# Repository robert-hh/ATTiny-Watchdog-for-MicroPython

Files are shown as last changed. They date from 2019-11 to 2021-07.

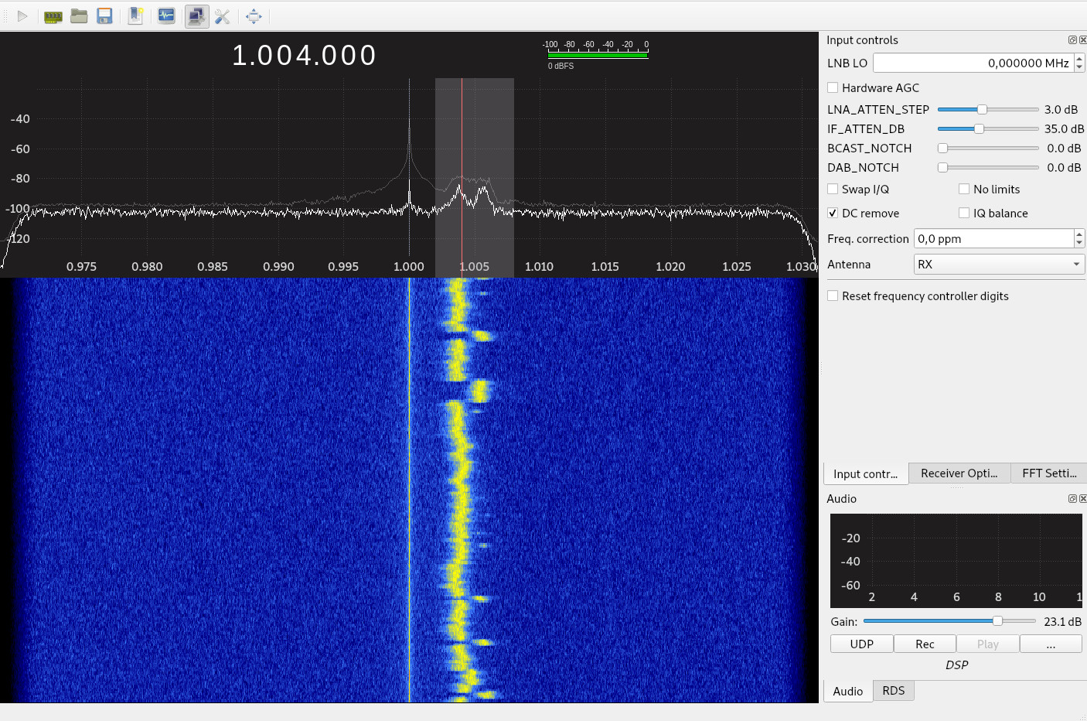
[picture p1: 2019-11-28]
Clock_1MHz.jpg

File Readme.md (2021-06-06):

# ATTiny based Watchdog (for MicroPython devices)

These are two variants of an external watchdog, which I made for use with ES32 based MicroPython
devices. Even if the ESP32 has a built-in watchdog, it is not really reliable. Actually, using
it does not improve the long term reliability of an application.

These two variants consists of two components:

- Software for an AttinyX5 device, which is the actual Watchdog. For (my) convenience
I made it with the Arduino development environment. I selected the ATTiny because it is easy 
available, cheap, well documented, and easy to use and available in various packages. 
Besides the controller and a pull-up resistor for the input, no other component is required.
- A small class for the MicroPython device controlling the watchdog.

These two variants differ on how the communication between the micropython device and
the watchdog is done.

- Pulse: Communication to the watchdog is via one GPIO line and pulses of various duration. 
That is the only drawback of using an external watchdog: it requires an GPIO port for feeding.
- Serial: Communication to the Watchdog is via one GPIO line and serial commands at 9600 baud.
Since only data is sent, I used the RMT module for sending, saving the UART port. For devices
without RMT a UART based variant is supplied.

The run-time overhead of both variants is comparable and differs only in the length of the 
feed pulse. For the **pulse** variant, it is 20µs, for the **serial** and **uart**  variant,
it is 100µs (the length of the start bit at 9600 baud).

Both watchdogs have two states, a sleep state and a watch state. They start in sleep state and have 
to be armed by a dedicated signal. The watch state can be suspended, e.g. before going to deep sleep.
The current consumption of the watchdog is about 1 µA, with short bursts of 1 mA for 500µs every second.

When the watchdog fires (Barks), it creates reset pulse of 100ms duration. For that time, the 
respective GPIO pin of the ATTiny will set to output mode. In all other times, it is in
input mode with pull-up active.

In both version, an Reset signal on the supervized micro is detected and will cause the watchdog 
to enter the sleep state. If the sleep state is timed (see command stop() below), then for that period only.

## Python class

### Serial version, RMT
watchdog = Watchdog(port, status=None, restart=False, baudrate=9600)

**Port** is the name or number of the GPIO port. It is important not to supply a pin
object, but the name, e.g. "P9" or 14. The GPIO pin will be initialized by the class.  
**status** is the name/number of a pin, which, if connected, can be used to read back the 
status of the watchdog. If the status pin is set,   
**restart**=True will cause a feed signal to be sent when status starts toggling,
which is when the watch period is halfway expired. This is useful in situations, when there is no
suitable place for a feed() call. The drawback: feed() is then called in a callback function, which
may even be executed when the to-be-supervized functions stoppped working.
**baudrate** is the speed to be used. The default is 9600 and hardly ever changed.

### Serial version, UART
watchdog = Watchdog(uart, status=None)

**uart** has be be an UART object created with the proper baud rate and pin assignments.  
**status** is a Pin object, defined in input mode for reading back the status pin.

### Pulse version
watchdog = Watchdog(port, status=None, restart=False)

**Port** is the name or number of the GPIO port. It is important not to supply a pin
object, but the name, e.g. "P9" or 14. The GPIO pin will be initialized by the class.  
**status** is the name/number of a pin, which, if connected, can be used to read back 
the status of the watchdog.  
**restart**=True will cause a feed signal to be sent when status starts toggling,
which is when the watch period is halfway expired. This is useful in situations, when there is no
suitable place for a feed() call. The drawback: feed() is then called in a callback function, which
may even be executed when the to-be-supervized functions stoppped working.  

## Methods

### watchdog.start(seconds)

Set the timeout period of the watchdog to seconds and start the watch mode. The granularity is seconds.
The shortest timeout period that can be set in the pulse version is about 15 seconds.

### watchdog.feed()

Feed the dog. The timeout time will be set to the value given by the start() command.
Do not call feed(), e.g. in a different thread, before the start() command terminated, 
which may take a while. After calling feed(), it takes about 2 ms until the status as reported by a
call to status() changes. 

### watchdog.stop(seconds=0)

Suspend the watch state for the given time and enter the sleep state. 
If the value of seconds is not zero, sleep only for that amount of time 
and return to the watch state after that.

### watchdog.status()

Read back the status of the watchdog using the pin set in the constructor. Return values:  

|Value|Meaning|
|:-:|:-|
|0|The watchdog is sleeping|
|1|The watchdog is active. If the watch period is halfway elapsed, the value gets togggling once per second. That can be used for instance to trigger a callback, which feeds the watchdog.|
|None|Port no set|

### watchdog.send(string)

Send string to the watchdog device using the baud rate set in the constructor. 
That is the basic command used by the methods start() and stop(). 
You can use that to toggle DEBUG output from the watchdog, by calling send("D").
In the pulse version, send() exists but does not do anything.

## Command interface of the ATTiny

### Pin assignments of the Attiny:

|Pin|Port|Function|
|:-:|:-:|:-|
|2|PB3|Reset signal to host (required)|
|3|PB4|Feed and command input pin (recommended)|
|4|GND|GND (required)|
|6|PB1|Status pin (optional)|
|7|PB2|Debug output pin. (optional)|
|8|Vcc|3.3 - 5V Vcc (required)|

### Serial interface

The following commands are supported: 

| Command | Description |
|:-:|:--|
|Snnn|Set the timeout of the watchdog and change to the watch state. nnn is the value in seconds. The command can be repeated while in watch state and will set a new timeout.|
|Pnnn|Suspend the watch state and return to the sleep state. If the number nnn is given and > 0, then sleep for that time only and return to the watch state after that.|
|Dn|n is a number, which may be omitted. If the value is 0, toggle the DEBUG output. If the value is not 0, switch DEBUG ouput on. The output is send to Port PB2 of the ATTiny with 9600 baud.|
|anything else|Feed the dog. For speed, the feed command actually only creates a start bit, and the ATTiny then reads 0xff as character.|

The DEBUG output of the ATTiny will echo the command and countdown the time in watch mode.  
The status output will indicate the watchdog state; low for sleeping and high for watching.

For the serial version a pull-up resistor at the communication link is highly recommended. The serial 
interface in the ATTiny uses the SoftSerial module of Arduino. It depends on the internal clock of 
the ATTiny (1 MHz here), which is not 100% accurate. In my test, the clock speed was 
about 1.005 MHz +/- 2 KHz. For asynchronous serial, that is still within the tolerated error range.

### Pulse interface

The following pulse time ranges are defined: 

|State| Duration| Description |
|:-:|:-:|:--|
|sleep|pulse < 5 ms|Feed pulse. Will be ignored|
|sleep|5 ms <= pulse < 10 ms|Stay in sleep mode. If after less than 10 ms it is followed by another pulse, that time is taken as sleep timeout.|
|sleep|10 ms <= pulse < 3600 ms|Set the timeout of the watchdog and change to the watch state. The pulse duration in ms defines the timeout value in seconds.|
|watch|20 µs < pulse < 5 ms|Feed the dog.| 
|watch|5 ms <= pulse < 10 ms|Suspend the watch state and enter the sleep state. If after less than 10 ms it is followed by another pulse, the length of that pulse is taken as sleep timeout.|
|watch|10 ms <= pulse < 3600 ms|Restart the watch state and set the new timeout.|

Pulses longer that 3600ms will be ignored in both states. That covers a line which is permanently low. The determination of the pulse duration is not very accurate, but good enough for the purpose.

The debug output will respond to the input with a series of pulses.   
- The first pulse length shows, if a internal timeout (~200µs) or a signal from the host (~1 ms) happened.   
- The second pulse shows the state of the watchdog, short for sleep and long for watch.   
- The third pulse shows the state of the reset line, short for high and long for low.  
- That is followed  by a burst of short pulses. The burst length indicates the remaining time until
timeout in the respective state. 

The status output will indicate the watchdog state; low for sleeping and high for watching.

## Example

Basic example:

```
import watchdog

wd = watchdog.Watchdog("P9")
wd.start(100) # set a timeout of 100 seconds and start
#
# To feed, call regularly
#
wd.feed()
#
# to stop, call
#
wd.stop()
```

Basic example using the internal callback for feeding:

```
import watchdog

wd = watchdog.Watchdog("P9", "P10", True)
wd.start(100) # set a timeout of 100 seconds and start
#
# No explicit call to feed is required
#
# to stop, call
#
wd.stop()
```

UART example using an dedicated callback for feeding:

```
import watchdog
from machine import UART, Pin

uart=UART(1, 9600)
pin = Pin("P10", Pin.IN)
wd = watchdog_uart.Watchdog(uart, pin)
pin.callback(Pin.IRQ_FALLING, handler=lambda p: wd.feed())

wd.start(100) # set a timeout of 100 seconds and start
#
# No explicit call to feed is required
#
# to stop, call
#
wd.stop()
```

## License

The MIT License (MIT)

Copyright (c) 2021 RobertHammelrath

Permission is hereby granted, free of charge, to any person obtaining a copy
of this software and associated documentation files (the "Software"), to deal
in the Software without restriction, including without limitation the rights
to use, copy, modify, merge, publish, distribute, sublicense, and/or sell
copies of the Software, and to permit persons to whom the Software is
furnished to do so, subject to the following conditions:
The above copyright notice and this permission notice shall be included in
all copies or substantial portions of the Software.

THE SOFTWARE IS PROVIDED "AS IS", WITHOUT WARRANTY OF ANY KIND, EXPRESS OR
IMPLIED, INCLUDING BUT NOT LIMITED TO THE WARRANTIES OF MERCHANTABILITY,
FITNESS FOR A PARTICULAR PURPOSE AND NONINFRINGEMENT. IN NO EVENT SHALL THE
AUTHORS OR COPYRIGHT HOLDERS BE LIABLE FOR ANY CLAIM, DAMAGES OR OTHER
LIABILITY, WHETHER IN AN ACTION OF CONTRACT, TORT OR OTHERWISE, ARISING FROM,
OUT OF OR IN CONNECTION WITH THE SOFTWARE OR THE USE OR OTHER DEALINGS IN
THE SOFTWARE.

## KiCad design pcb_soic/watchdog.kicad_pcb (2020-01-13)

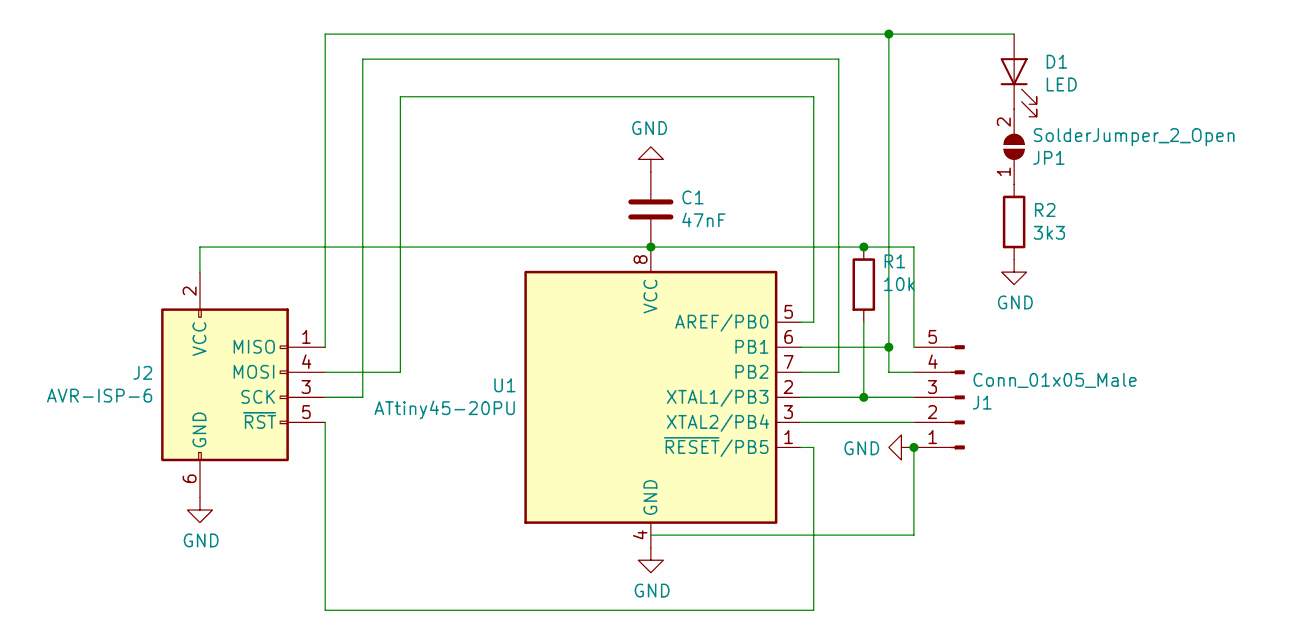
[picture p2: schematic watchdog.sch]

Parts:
C1: 47nF; C_1206_3216Metric_Pad1.42x1.75mm_HandSolder
D1: LED; LED_1206_3216Metric_Pad1.42x1.75mm_HandSolder
J1: Conn_01x05_Male; PinHeader_1x05_P2.54mm_Vertical
J2: AVR-ISP-6; PinHeader_2x03_P2.54mm_Vertical
JP1: SolderJumper_2_Open; SolderJumper-2_P1.3mm_Open_TrianglePad1.0x1.5mm
R1: 10k; R_1206_3216Metric_Pad1.42x1.75mm_HandSolder
R2: 3k3; R_1206_3216Metric_Pad1.42x1.75mm_HandSolder
U1: ATtiny45-20PU; DIP-8_W7.62mm

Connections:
GND: C1.1, J1.1, J2.6 (GND), R2.2, U1.4 (GND)
unnamed: C1.2, J1.5, J2.2 (VCC), R1.1, U1.8 (VCC)
unnamed: D1.1 (K), JP1.2 (B)
unnamed: D1.2 (A), J1.4, J2.1 (MISO), U1.6 (PB1)
unnamed: J1.2, U1.3 (XTAL2/PB4)
unnamed: J1.3, R1.2, U1.2 (XTAL1/PB3)
unnamed: J2.3 (SCK), U1.7 (PB2)
unnamed: J2.4 (MOSI), U1.5 (AREF/PB0)
unnamed: J2.5 (~RST), U1.1 (~RESET~/PB5)
unnamed: JP1.1 (A), R2.1

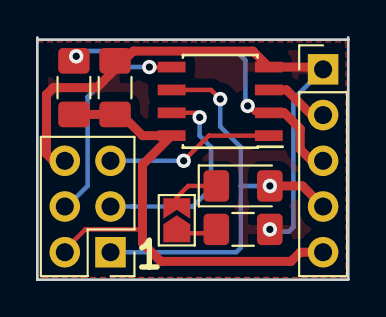
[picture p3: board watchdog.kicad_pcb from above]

Board: 2 copper layers, 17.3 x 13.5 mm, 8 parts (0 on the bottom side), 10 nets.

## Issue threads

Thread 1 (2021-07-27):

wrong pin-numbering in attiny-code for pulse-version

l0j0, 2021-07-27:
it seems the pin numbers in the pulse-version of the attiny code (watchdog.ino) are exchanged:
it reads:
#define FEED_PIN 3
#define DEBUG_PIN 2
#define STATUS_PIN 1
#define RESET_PIN 4

but should be (also according readme and kicad schema):
#define FEED_PIN 4
#define DEBUG_PIN 2
#define STATUS_PIN 1
#define RESET_PIN 3

thanks for this great project btw!

robert-hh, 2021-07-28:
Thank you for the note. It may be, that I changed the pin assignment for an easier Board layout. I'll change that.

robert-hh, 2021-07-29:
Changed. And thank you very much for the hint.

Closed 2021-07-29.

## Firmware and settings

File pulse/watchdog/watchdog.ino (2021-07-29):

/*
 *
 * The MIT License (MIT)
 *
 * Copyright (c) 2021 RobertHammelrath
 *
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
 * THE SOFTWARE IS PROVIDED "AS IS", WITHOUT WARRANTY OF ANY KIND, EXPRESS OR
 * IMPLIED, INCLUDING BUT NOT LIMITED TO THE WARRANTIES OF MERCHANTABILITY,
 * FITNESS FOR A PARTICULAR PURPOSE AND NONINFRINGEMENT. IN NO EVENT SHALL THE
 * AUTHORS OR COPYRIGHT HOLDERS BE LIABLE FOR ANY CLAIM, DAMAGES OR OTHER
 * LIABILITY, WHETHER IN AN ACTION OF CONTRACT, TORT OR OTHERWISE, ARISING FROM,
 * OUT OF OR IN CONNECTION WITH THE SOFTWARE OR THE USE OR OTHER DEALINGS IN
 * THE SOFTWARE.
 */

/* 
   Soft Watchdog Timer
   Receives both Feed pulse and Commands from Pin 4
*/
   
#include <avr/sleep.h>
#include <avr/interrupt.h>
#include <avr/power.h>
#include <avr/wdt.h>

#define FEED_PIN 4
#define DEBUG_PIN 2
#define STATUS_PIN 1
#define RESET_PIN 3

#define DEBUG 0

#define MAX_PULSE 3600
#define SUSPEND_PULSE 5 

// Globals
// if you want to start the watchdog busy, set sleep period and watch period accordingly.
// then it needs no further interaction to run.
//
int watch_period = 3600; // Default timeout 1 hour. Sleepy dog
int sleep_period = 0;    // Default timeout infinite
int timer = sleep_period;
int tick_seen = 0;
enum {
  SLEEPING, WATCHING
} state = SLEEPING; 

enum tags {
  TIMEOUT = 'T',
  START = 'S',
  STOP = 'P',
  FEED = 'F',
  LOGGING = 'D'
};

// Function and Data Prototypes
struct result {
    tags cmd;
    int value;
};
void system_sleep(int duration, int mode) ;
int get_pulsetime(int, int, int);
result get_input();
#if DEBUG
void send_ack(int, int);
void send_burst(int, int);
#endif

void setup() {
    pinMode(RESET_PIN, INPUT_PULLUP);
    pinMode(FEED_PIN, INPUT_PULLUP);
    pinMode(STATUS_PIN, OUTPUT);
#if DEBUG
    pinMode(DEBUG_PIN, OUTPUT);
#endif
    state = SLEEPING;
}

void loop() {
    result input;
    int reset_state;

    if (state == SLEEPING) {
      digitalWrite(STATUS_PIN, LOW);
    } else {
      if (timer < (watch_period / 2)) {
        digitalWrite(STATUS_PIN, timer & 1); // toggle status
      } else {
        digitalWrite(STATUS_PIN, HIGH);
      }
    }

    system_sleep(WDTO_1S, SLEEP_MODE_PWR_DOWN);

    reset_state = digitalRead(RESET_PIN); // could be reset of the master which happened
    input = get_input();
    if (reset_state == 0) { // reset forces Sleep or Feed??
        state = SLEEPING;
        timer = sleep_period;
    } else {
      switch (input.cmd) {
        case START:
          state = WATCHING;
          timer = watch_period = input.value;
          break;
        case STOP:
          state = SLEEPING;
          timer = sleep_period = input.value;
          break;
        case FEED:
          if (state == WATCHING) { // Feed the dog
            timer = watch_period;
          }
          break;
        case TIMEOUT: // 1 s Timer 
        default:  // can only be timeout of timer.
          if (state == SLEEPING) { // Suspended or startup
            if (sleep_period > 0) {
              timer -= 1;
              if (timer <= 0) {
                timer = watch_period;
                state = WATCHING;
              }
            }
          } else if (state == WATCHING) {  // Armed
            timer -= 1;
            if (timer <= 0) {
        
              pinMode(RESET_PIN, OUTPUT);
              digitalWrite(RESET_PIN, LOW);
              delay(100);
              digitalWrite(RESET_PIN, HIGH);
              pinMode(RESET_PIN, INPUT_PULLUP);
        
              state = SLEEPING;
              timer = sleep_period;
              // if the watchdog should be restarted instead of sleeping,
              // replace the two lines above by the single line
              // timer = watch_period;
            }
            break;
          }
      }
    }    
#if DEBUG    
    if (DEBUG) {
      send_ack(DEBUG_PIN, tick_seen);
      send_ack(DEBUG_PIN, state);
      send_ack(DEBUG_PIN, 1 - reset_state);
      send_burst(DEBUG_PIN, timer);
    }
#endif
}

result get_input()
{
  int pulse_time;
  result input;

  if (tick_seen) { // pulse seen; 
    pulse_time = get_pulsetime(FEED_PIN, LOW, MAX_PULSE);
    if (pulse_time < SUSPEND_PULSE) { // Short pulse, feed signal
      input = {FEED, 0};
    } else if (pulse_time >= SUSPEND_PULSE && pulse_time < (SUSPEND_PULSE * 2)) {
      get_pulsetime(FEED_PIN, HIGH, SUSPEND_PULSE * 2);
      input = {STOP, get_pulsetime(FEED_PIN, LOW, MAX_PULSE)}; // Stop signal
    } else if (pulse_time >= (SUSPEND_PULSE * 2) && pulse_time < (MAX_PULSE - 2)) { // start watch
      input = {START, pulse_time};  // Start signal
    } 
  } else { // No pulse, timeout of 1s timer.
    input = {TIMEOUT, 0};
  }
  return input;
}

int get_pulsetime(int pin, int level, int maxtime)
{
    unsigned long start, now;
    unsigned long then = (unsigned long)maxtime * 1000;

    now = start = micros();
    while ((now - start) < then) {
      if (digitalRead(pin) != level) {
        break;
      }
      now = micros();
    }
    return (int)((now - start + 500) / 1000);
}

#if DEBUG
void send_ack(int pin, int duration)
{
    digitalWrite(pin, HIGH);
    delay(duration);
    digitalWrite(pin, LOW);
}

void send_burst(int pin, int burst)
{
    for (int i = 0; i < burst; i++) {
    digitalWrite(pin, HIGH);
    digitalWrite(pin, LOW);
    }
}
#endif
//****************************************************************  
// set system into the sleep state 
// system wakes up when wtchdog is timed out
void system_sleep(int duration, int mode) 
{
    tick_seen = 0;
    GIMSK |= _BV(PCIE);                     // Enable Pin Change Interrupts
    PCMSK |= (_BV(PCINT4) | _BV(PCINT3));   // Use PB3 and PB4 as interrupt pin
    wdt_enable(duration);
    set_sleep_mode(mode); // sleep mode is set here
    wdt_reset();
#ifdef _AVR_IOTNX5_H_  
    WDTCR |= (1<<WDIE); // reenable interrupt to prevent system reset
    ADCSRA &= ~_BV(ADEN);                     //disable ADC
#else    
    WDTCSR |= (1<<WDIE); // reenable interrupt to prevent system reset
#endif
    sei();                                  // Enable interrupts
    sleep_enable();
    sleep_cpu();
    cli();                                  // Disable interrupts
    PCMSK &= ~(_BV(PCINT4) | (_BV(PCINT3)));               // Turn off PB4 as interrupt pin
    sleep_disable();                     // System continues execution here when watchdog timed out 
#ifdef _AVR_IOTNX5_H_  
    ADCSRA |= _BV(ADEN);                 //enable ADC
#endif    
    sei();                                  // Enable interrupts
}

//****************************************************************  

ISR(WDT_vect) 
{
   wdt_disable();
}

ISR(PCINT0_vect) {
    // This is called when the interrupt occurs; Just set the flag to notice
    tick_seen = 1;
}

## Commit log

2019-11-28 Watchdog: Two versions of an ATTinyx5 based watchdog timer
    For instance to be used in combination with MicroPython devices.
2019-11-29 watchdog.ino: Make the pulse variant restartable
    In both states, suspend switched to sleep() mode and set() starts or
    restarts the timer.
    Other changes:
    - A status method for the pulse variant.
    - A watchdog_uart.py variant for the serial interface, which uses
    a uart instead of the RMT module fpr communication.
2019-11-29 serial/watchdog.py: Fix glitch
    Additional: add dummy status() method to match the pulse variant.
    [watchdog.py]
2019-11-30 pcv/*: A Kicad Layout for a small board
    In cased that it is to be added to an existing set-up, I sketched this
    board. All with big component for hand soldering. It has a AVR-ISP
    connecro area too, which take 30% of the board.
    [_saved_watchdog.sch, watchdog.kicad_pcb, watchdog.sch]
2019-11-30 watchdog: Major rework
    serial variant: Support now the status() command
    both variants: Detect a manual reset on the reset line and stop
    the watchdog. Assuming it will be re-started after devuce start-up.
    [watchdog.ino, watchdog.py, watchdog_uart.py]
2019-11-30 pcb: small change to the PCB
    [watchdog.kicad_pcb]
2019-12-01 watchdog: Rework and cleaning
    pulse/watchdog.py:
    - add the dummy argument to stop(), and make send() cause a feed signal
    pulse/watchdog/watchdog.ino:
    - clean up the code. Remove unused variables
    serial/watchdog.py:
    serial/watchdog_uart.py:
    - Add support for an time argument of the stop() method
    serial/watchdog/watchdog.ino:
    - clean up the code, by removing unsused variables and reducing the
    number of global variables
    - add support for a timed stop state. The parameter of stop command
    tells the time the sleep state will last.
    Readme.me: Document the API and interface changes.
    [watchdog.ino, watchdog.py, watchdog_uart.py]
2019-12-02 watchdog: Major rework of the Arduino files
    Both files now are mostly similar, with the exception of the interface
    handling. The timed sleep method was also added to the pulse version.
    The documentation was changed and extended to reflect the code change.
    [watchdog.ino, watchdog.py]
2019-12-05 watchdog/pulse: Change method for timing the pulse
    Instead of counting delays, micros() is used to time
    the command pulse.
    Also: change the method in pyboard.py to create the command pulse,
    since utime.sleep_ms() has too much jitter; it is: time -1/+0.5 ms.
    Using consecutive calls of utime.sleep_us(950) give better results.
    [watchdog.ino, watchdog.py]
2019-12-05 watchdog.ino: Swapped pin 3 and 4
    I had a bug in my PCB and already made samples, and it is easier to
    change the code than the PCB. At least just now.
    [_saved_watchdog.sch]
2019-12-06 watchdog.py, pulse variant: Fore a minimal watch time
    Otherwise, a start() signal looks like a stop() signal.
    Also: Minor change on the PCB. Add a label and make the board
    just a little bit smaller by narrowing the edges.
    [watchdog.kicad_pcb]
2019-12-20 pcb: Change layout.
    Rotate Attiny by 90°
    [watchdog.kicad_pcb]
2019-12-20 pcb_soic: Add smaller PCB with SMD components
    Large components are used, such that hand soldering is still possible.
    A LED was added to the board too showing the state (if required).
    The size of the PCB is now 13x17mm (was 14x20mm before). Most of the
    space is used by the connectors.
    [watchdog.kicad_pcb, watchdog.sch]
2020-01-13 serial/watchdog*: Add RMT variant for the mp.org version
    Also:
    Rename the serial/watchdog.py version
    [watchdog.kicad_pcb]
2021-07-29 Watchog Pulse: Swap Reset and Feed pin numbers.
    That neede to be changed matching the sample PCB layout. Thanks to
    User @l0j0 for notifying.
    [watchdog.ino]
